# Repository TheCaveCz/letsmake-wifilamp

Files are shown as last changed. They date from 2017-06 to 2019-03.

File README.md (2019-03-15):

# Let's make: WiFi Lamp

ESP8266 chip on Wemos D1 mini module that is driving WS2812 LED strip, one tactile switch for manual control.
Firmware contains HTTP REST API and Blynk platform integration for mobile app control.

More resources:
* [3D prints](stl)
* Firmware
  * [Original](firmware/lm-wifilamp) - uses [Arduino core for ESP8266](https://github.com/esp8266/Arduino), using [Blynk](https://blynk.cc) platform
  * [Tester](firmware/lm-wifilamp-test) - testing sketch
* [Hardware assembly](pictures)
* [PCB drawings](board) - simple PCB to avoid messing with lots of wires. Created in EAGLE 7.7

## Setup

### On your computer

* Install [Arduino core for ESP8266](https://github.com/esp8266/Arduino#installing-with-boards-manager) - **use version 2.4.2 or above**
* Install the [Blynk Arduino library](http://help.blynk.cc/getting-started-library-auth-token-code-examples/how-to-install-blynk-library-for-arduino)
* Install the [WiFi Manager library](https://github.com/tzapu/WiFiManager)
* Compile and upload the [firmware](firmware/lm-wifilamp)

### On your mobile phone

* Install [Blynk app](https://www.blynk.cc/getting-started/)
* Create account or log in
* Create new empty project in Blynk App
* Copy auth token from the app or your email
* Connect to the wifilamp AP
* Wait for WiFi login popup (or use browser and navigate to `http://192.168.4.1`)
* Enter WiFi credentials and auth token
* Setup the Blynk project (see next section)

### Reconfiguring or resetting lamp

* Hold button until the lamp lights up with violet color
* Connect to the wifilamp AP
* Wait for WiFi login popup (or use browser and navigate to `http://192.168.4.1`)
* Enter WiFi credentials and auth token

## Blynk project

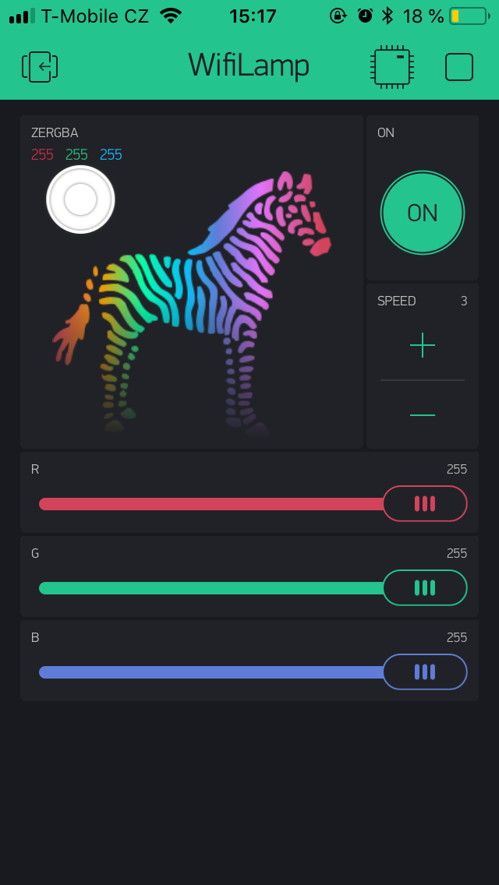
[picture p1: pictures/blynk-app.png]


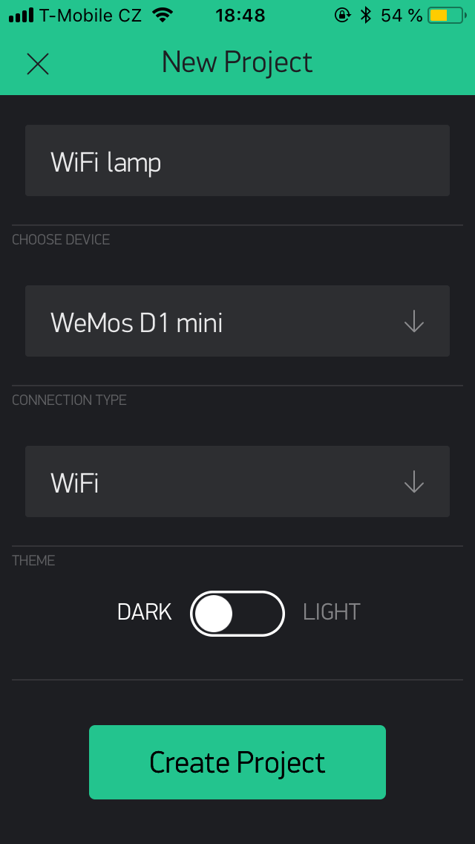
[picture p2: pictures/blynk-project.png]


[Check the video of creating the Blynk project](pictures/blynk-setup.mp4)

<video width="320"><source src="pictures/blynk-setup.mp4" type="video/mp4"></video>

## How it looks

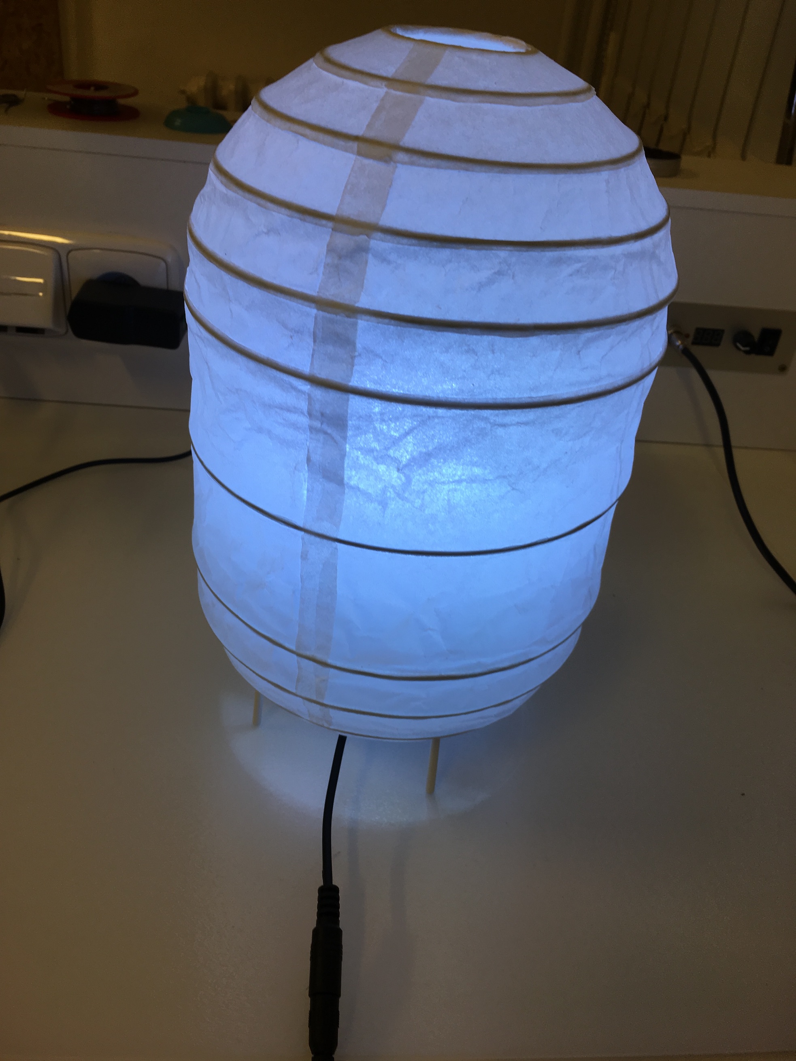
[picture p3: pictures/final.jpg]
The Device


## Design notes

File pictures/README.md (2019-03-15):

# Assembly instructions

## Button box

Slide longer cable assembly into the heat shrink tube. All the way up to the connector
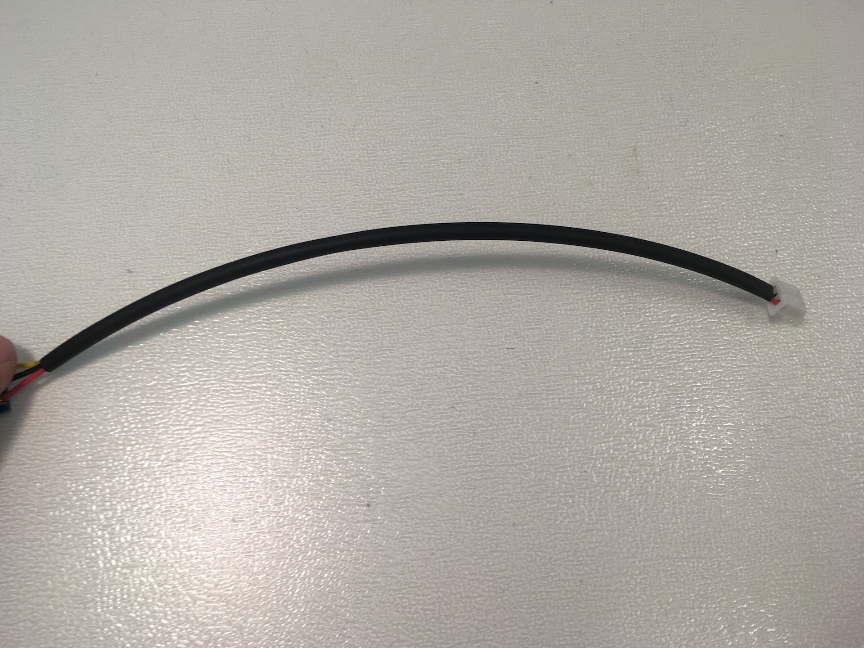
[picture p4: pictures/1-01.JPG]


Solder the wires sticking from the heat shrink tube to the PCB. Mind the correct colors!
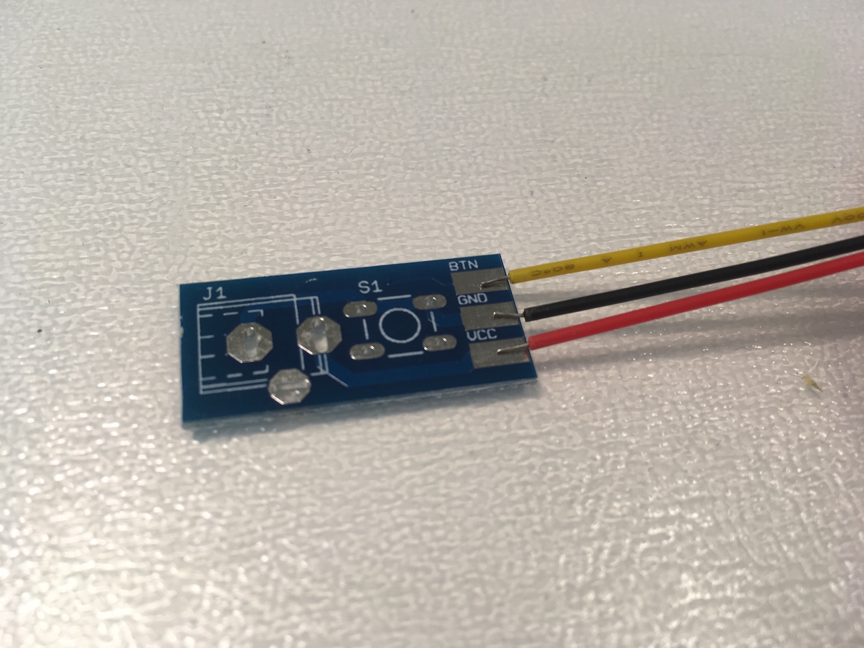
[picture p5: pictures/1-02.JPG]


Solder button and DC jack to the PCB. DC jack needs to lie flat and straight on the PCB. Same for the connector.
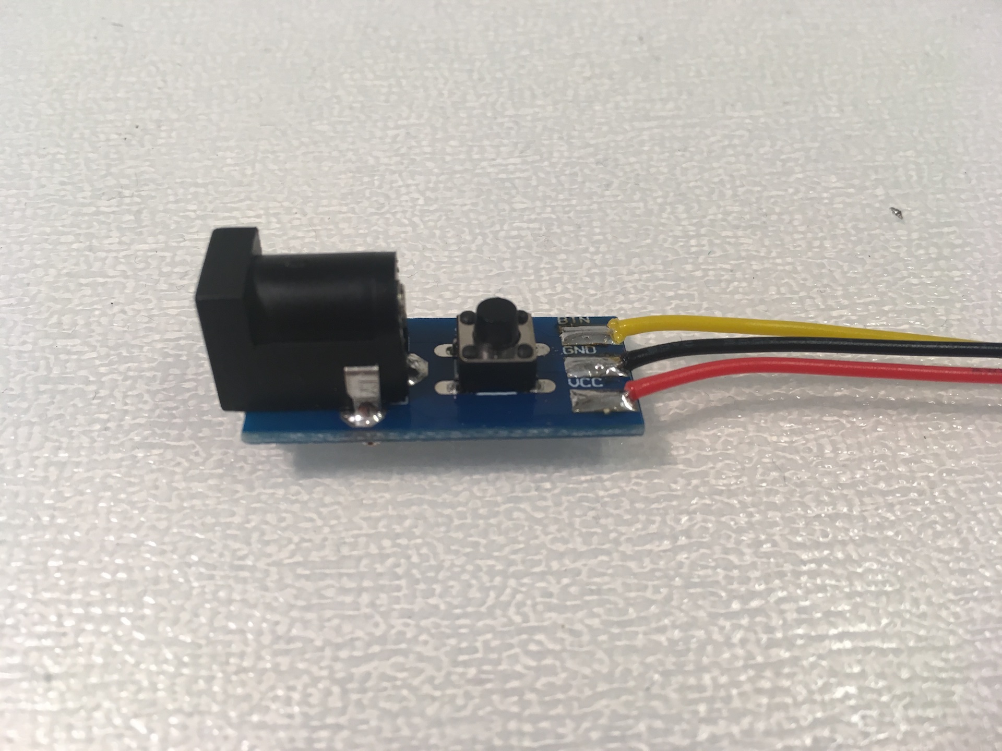
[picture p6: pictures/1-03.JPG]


Move the heatshrink tube all the way to the PCB and shrink it using heat (regular lighter is OK). Place the PCB into the bottom part of the box. It needs to fit precisely into the printed slot in the box.
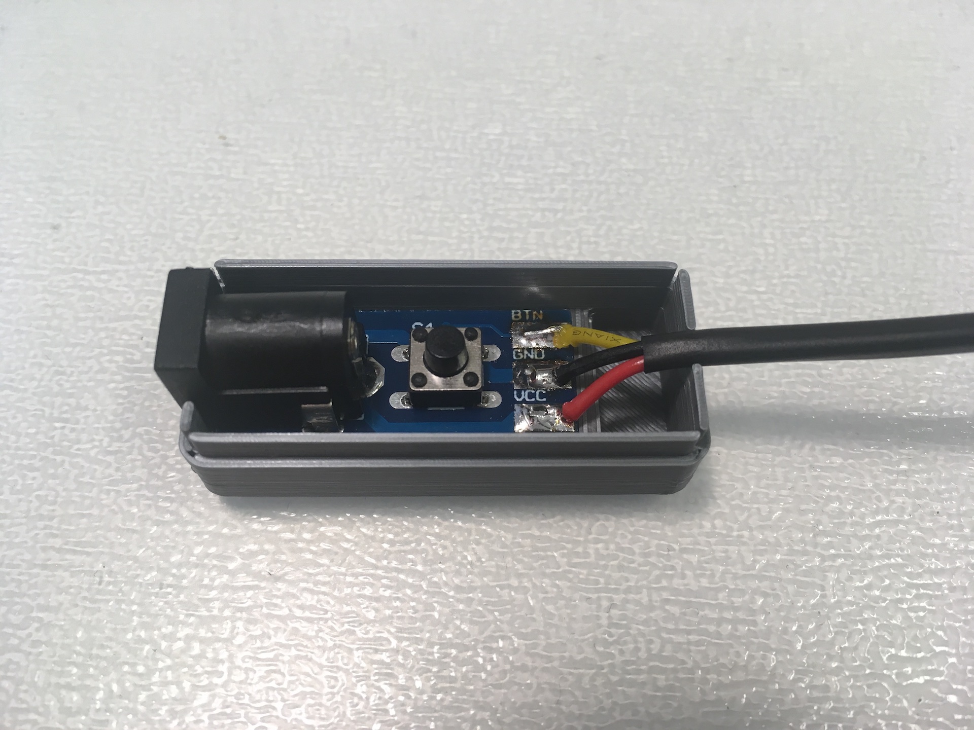
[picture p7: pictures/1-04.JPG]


Place the knob on the switch and cover the box with top part. Button needs to click freely and loudly after the box is closed.
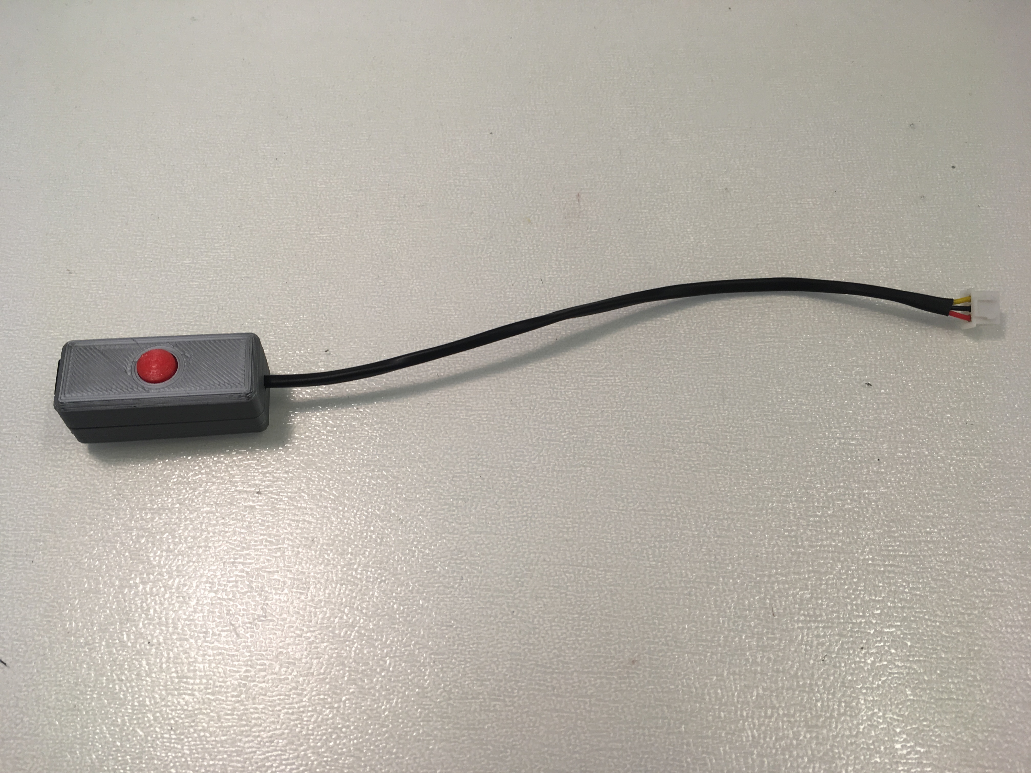
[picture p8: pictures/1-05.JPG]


## LED holder

Solder the wires of the shorter cable assembly onto the LED strip. Mind the correct colors!
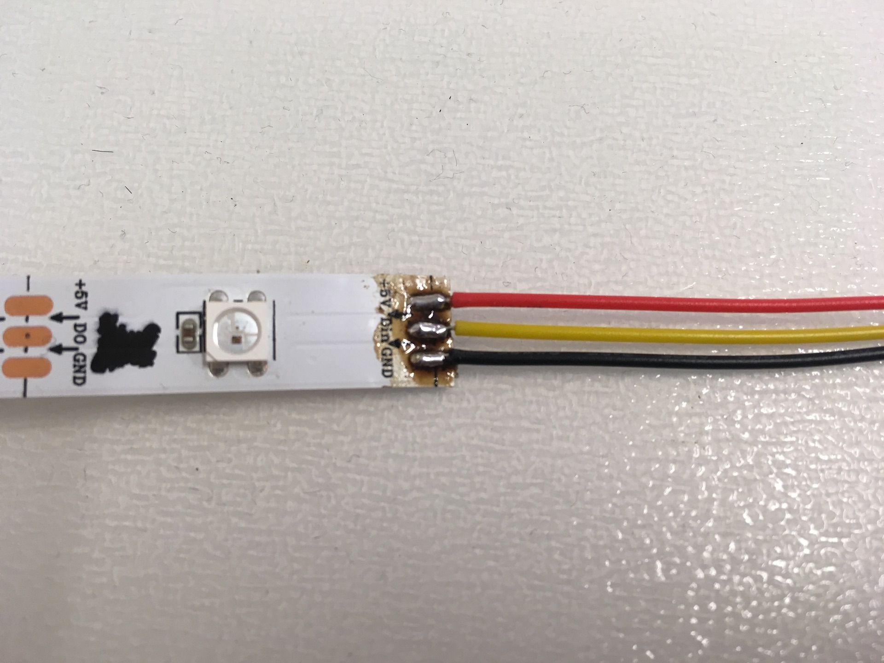
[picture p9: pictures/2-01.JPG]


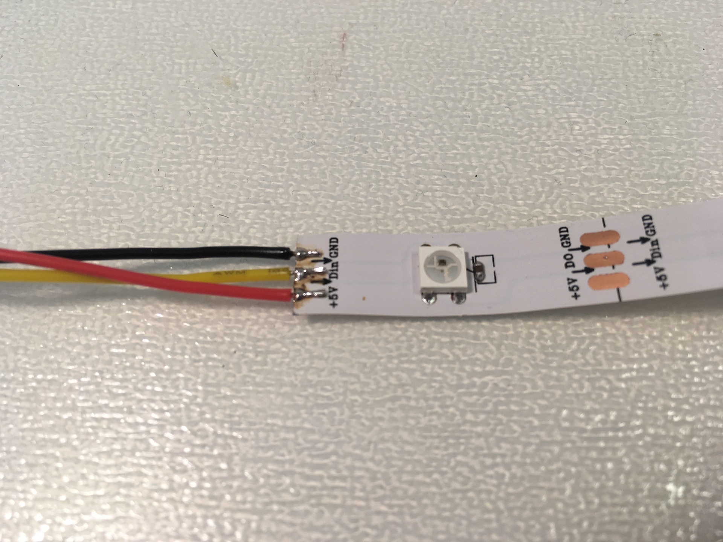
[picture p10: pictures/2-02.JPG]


Stick one piece of paper tape on the top of the aluminium tube.
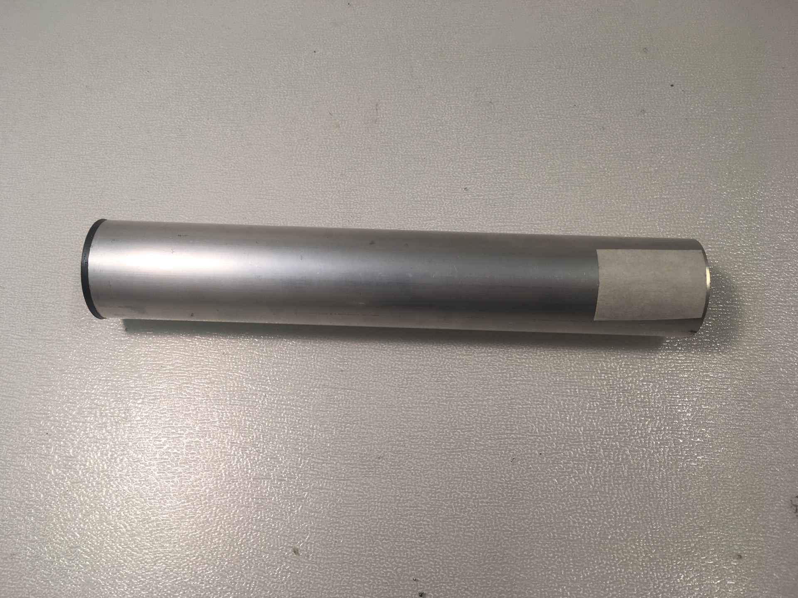
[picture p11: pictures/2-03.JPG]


Stick the LED strip on the tube. Do not stick it all the way to the end for now! Strip must start on the paper tape!
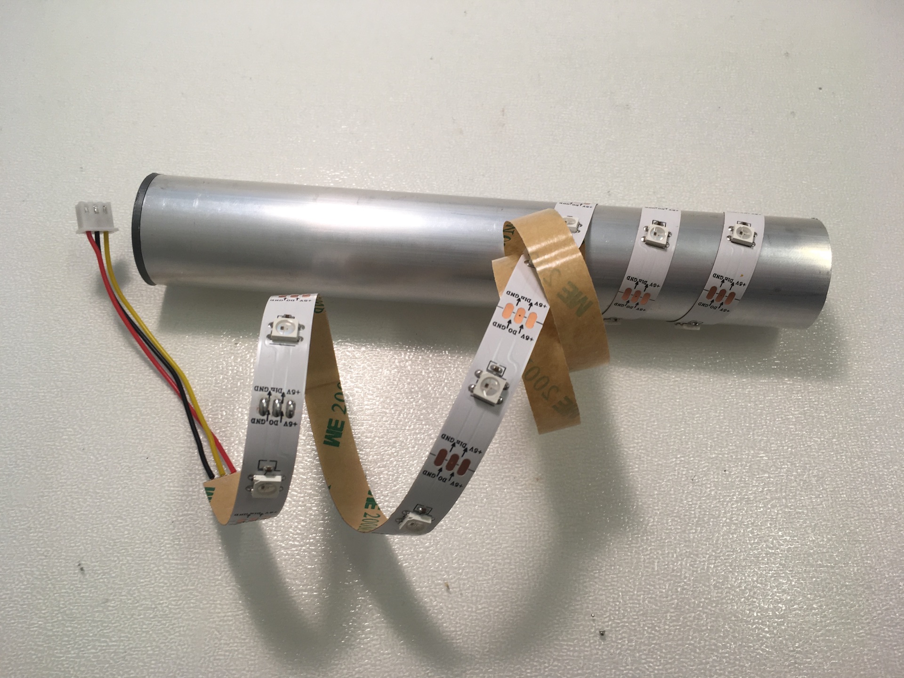
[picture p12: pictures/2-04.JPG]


Stick one piece of paper tape on the place where LED strip will end.
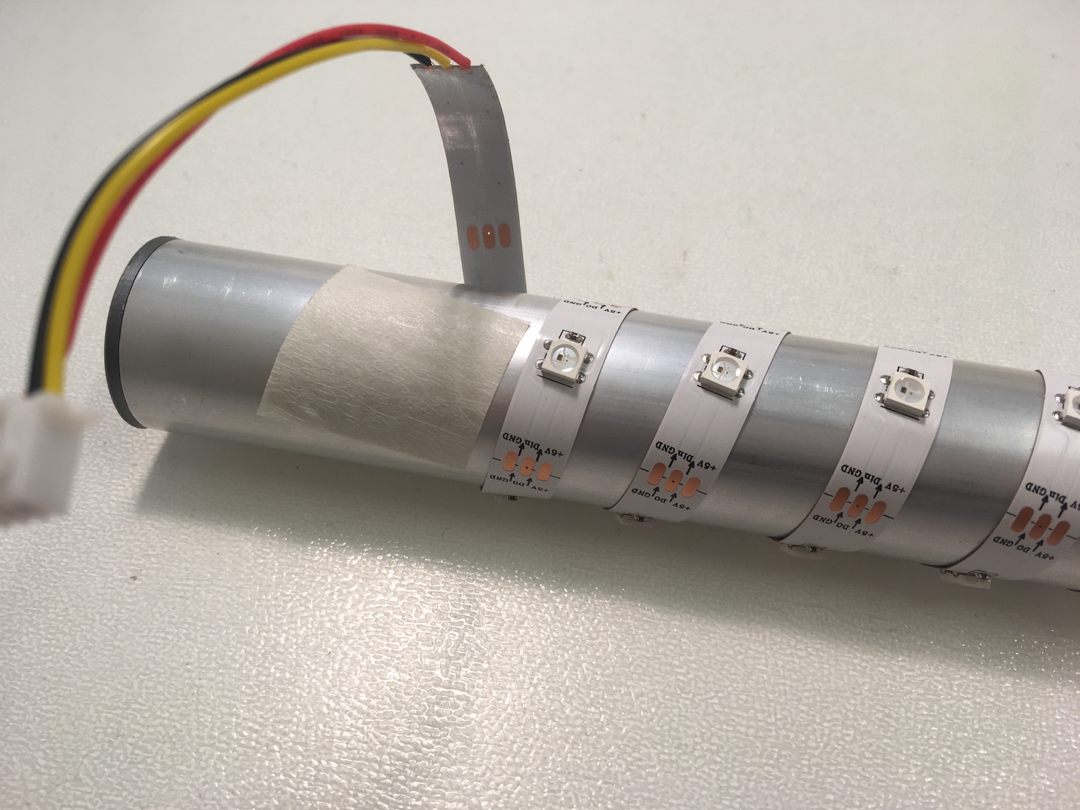
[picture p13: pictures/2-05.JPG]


Finish the LED strip - end of the LED strip must be on the paper tape!
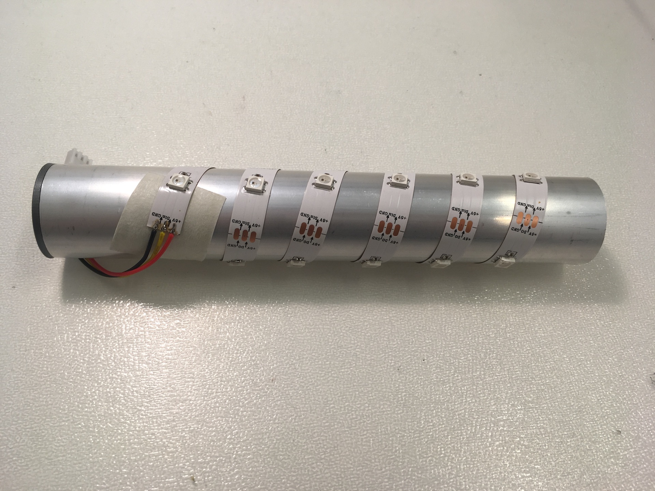
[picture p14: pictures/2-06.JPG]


Secure start of the strip with piece of paper tape.
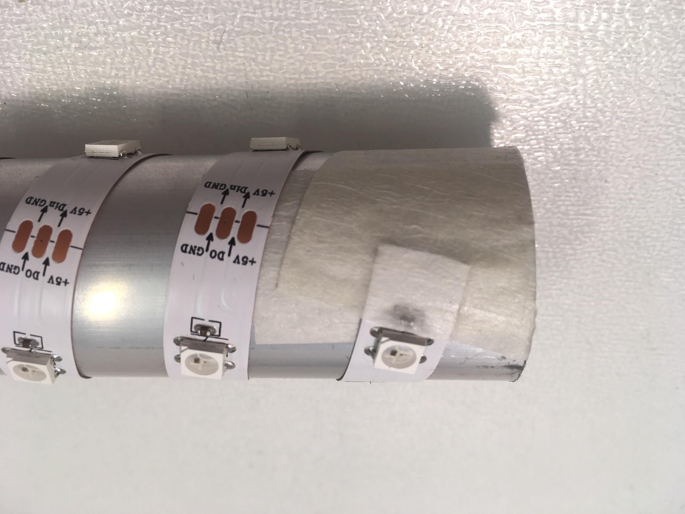
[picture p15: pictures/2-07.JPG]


Secure end of the strip with piece of paper tape.
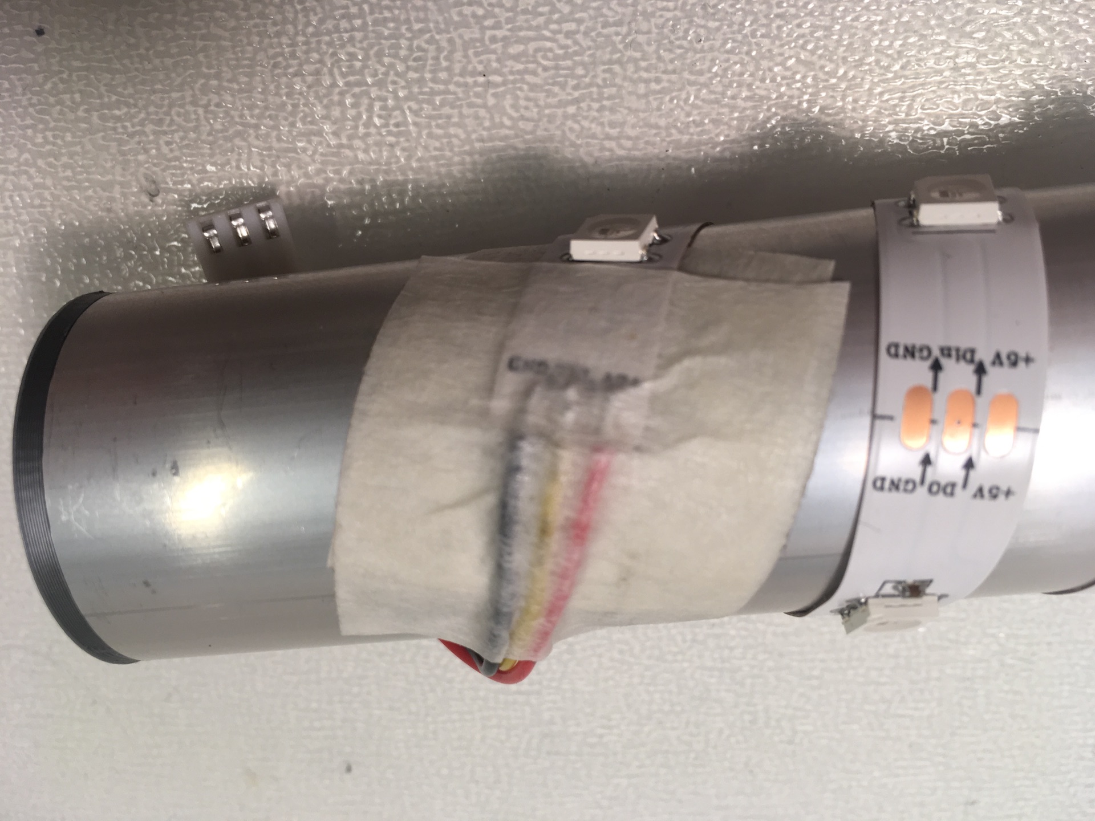
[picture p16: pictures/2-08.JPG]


## Base

Put pin headers into the PCB. Short part of the pin header must face up, long part is in the PCB. Do not solder anything yet!
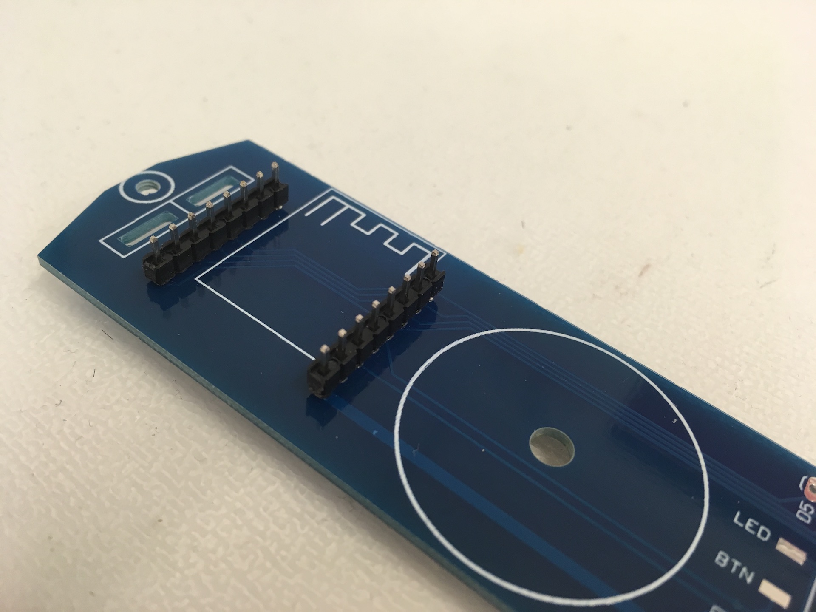
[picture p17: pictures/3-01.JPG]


Place Wemos D1 mini on the short part of the pin headers and solder pin headers to Wemos D1 mini.
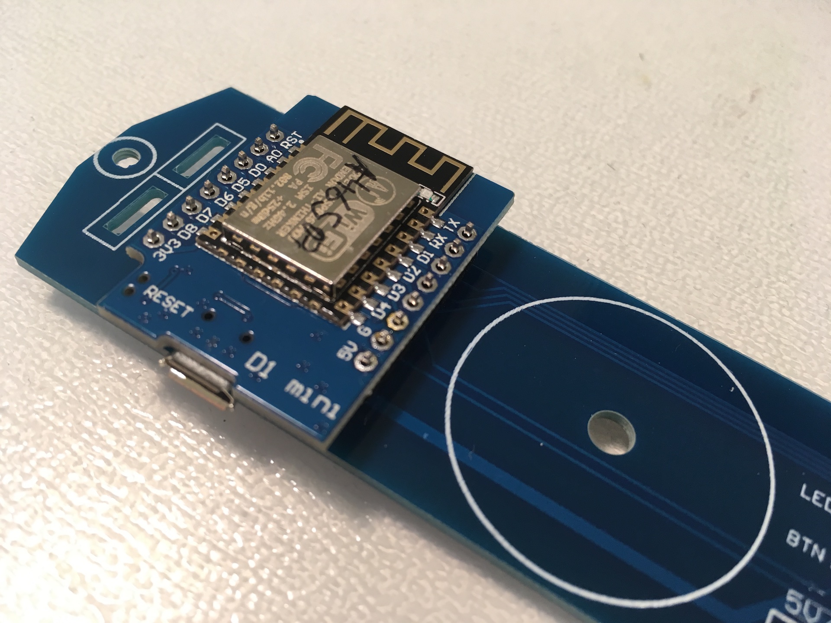
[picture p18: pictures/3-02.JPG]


Pull Wemos D1 mini from the PCB and put at aside for a while.
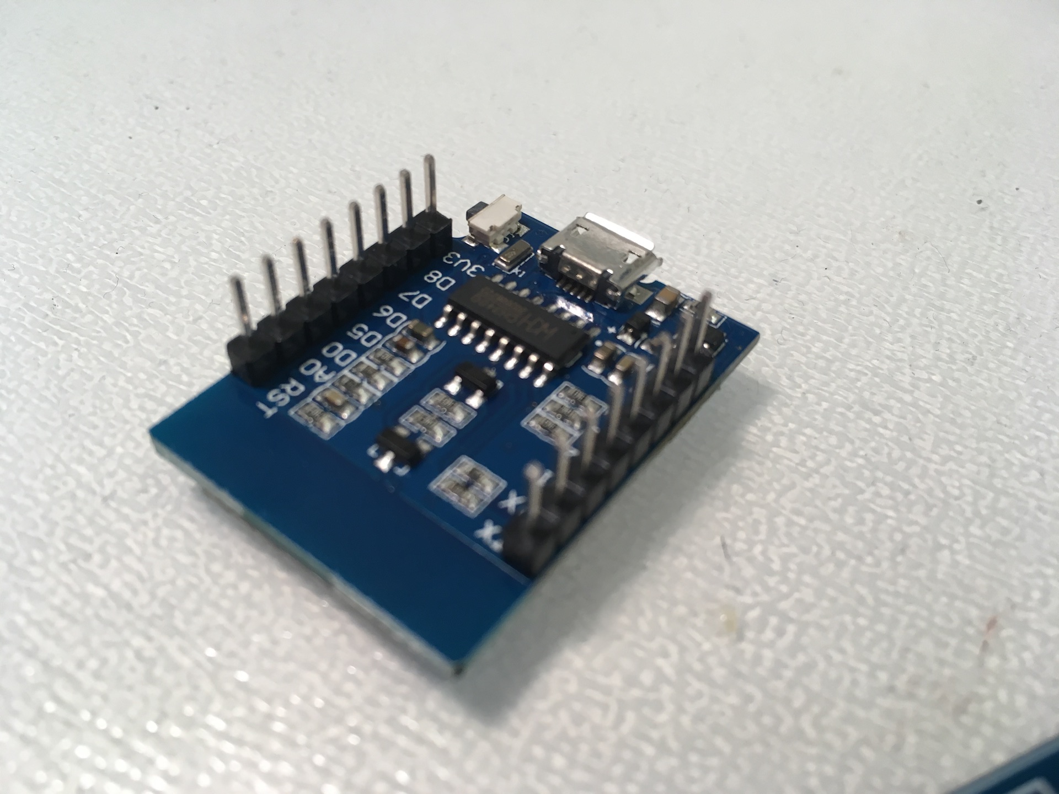
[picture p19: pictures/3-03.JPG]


Solder angle JST connector to the PCB (opening marked PWR). Connector must face out of the PCB
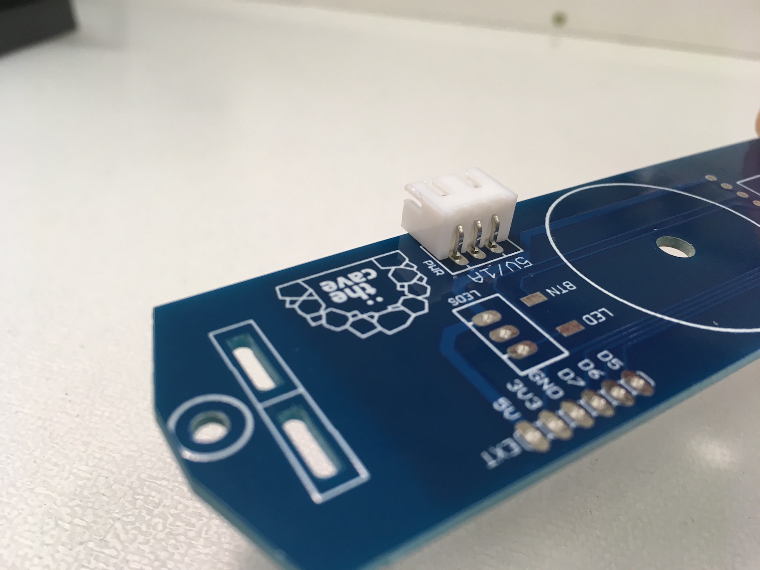
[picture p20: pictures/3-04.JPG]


Solder straight JST connector to the PCB (opening marked LEDS). Mind the correct orientation (connector must line perfectly with the outline on the PCB).
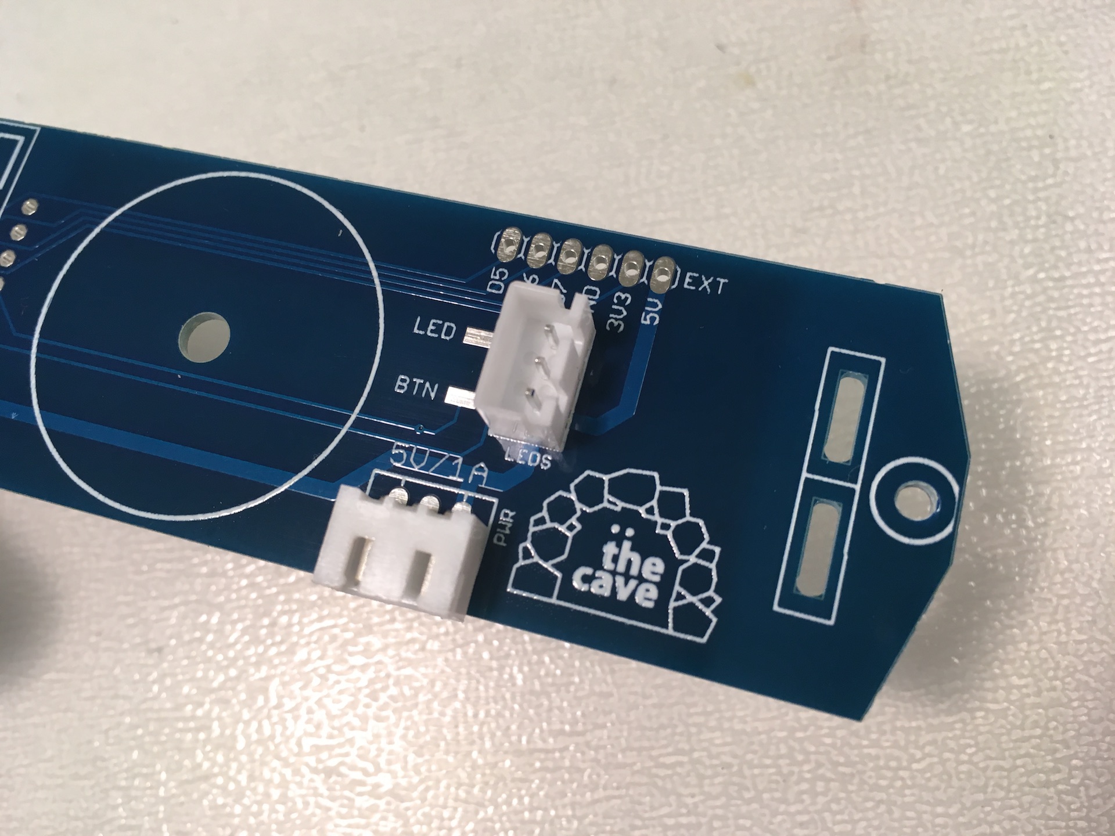
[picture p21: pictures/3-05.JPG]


Put pin header sockets on Wemos D1 mini
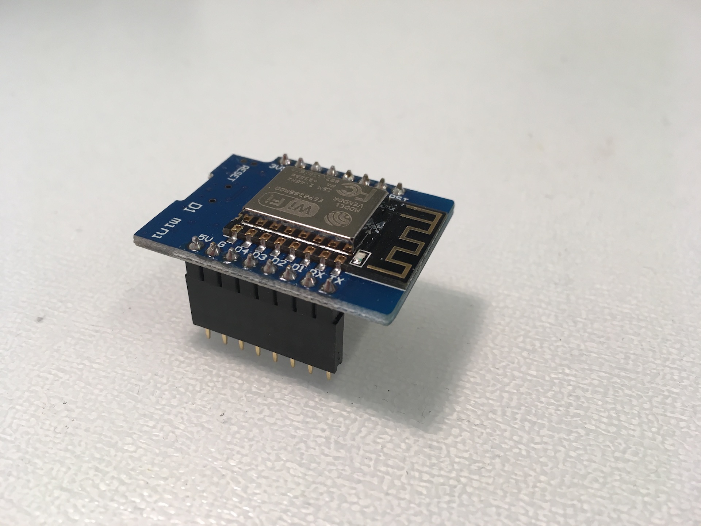
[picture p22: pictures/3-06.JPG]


Solder Wemos D1 mini with sockets to the PCB. Wemos antenna (gold wiggly line) must match with the drawing on the PCB.
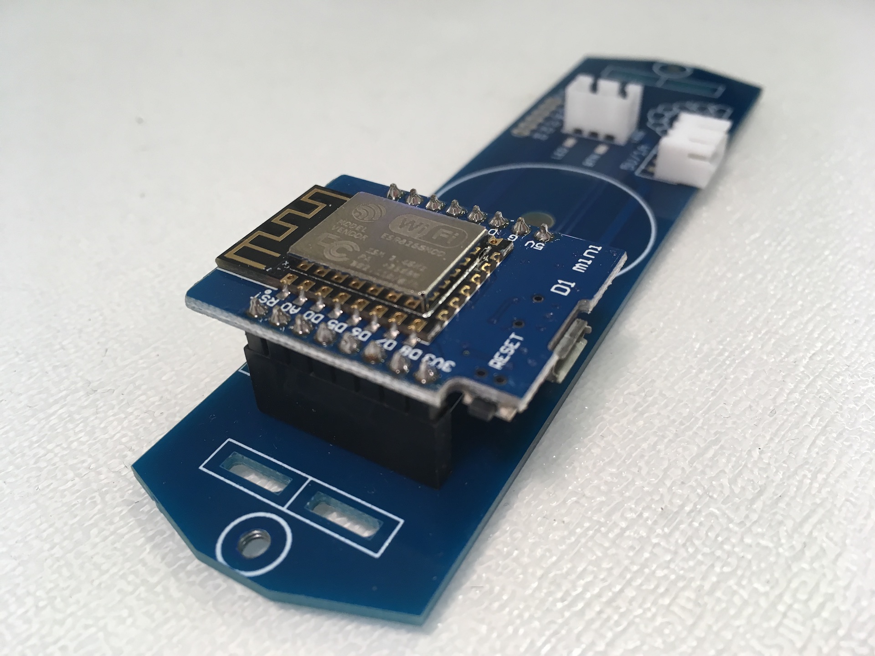
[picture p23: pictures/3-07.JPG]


Pull Wemos D1 mini out of the socket.
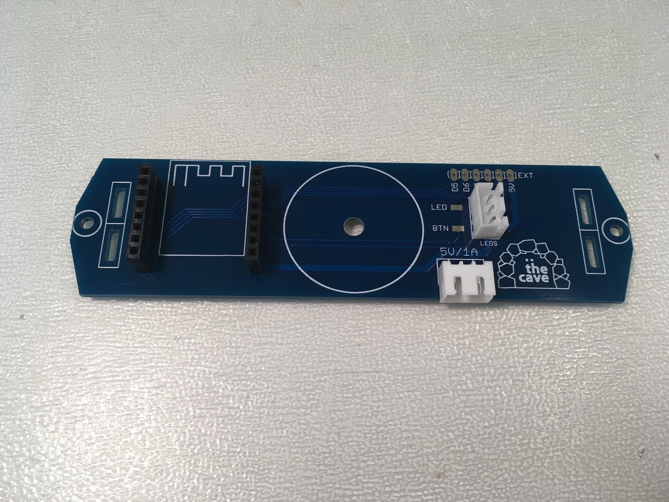
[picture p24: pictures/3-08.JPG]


Put M4 nut into the 3D printed circular holder.
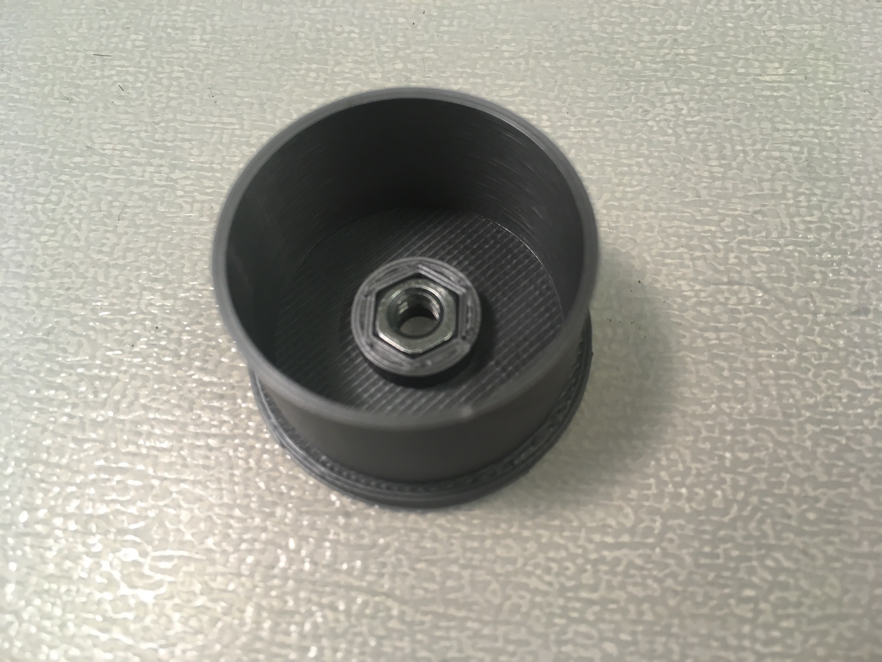
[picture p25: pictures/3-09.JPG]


Put M4 screw into the PCB.
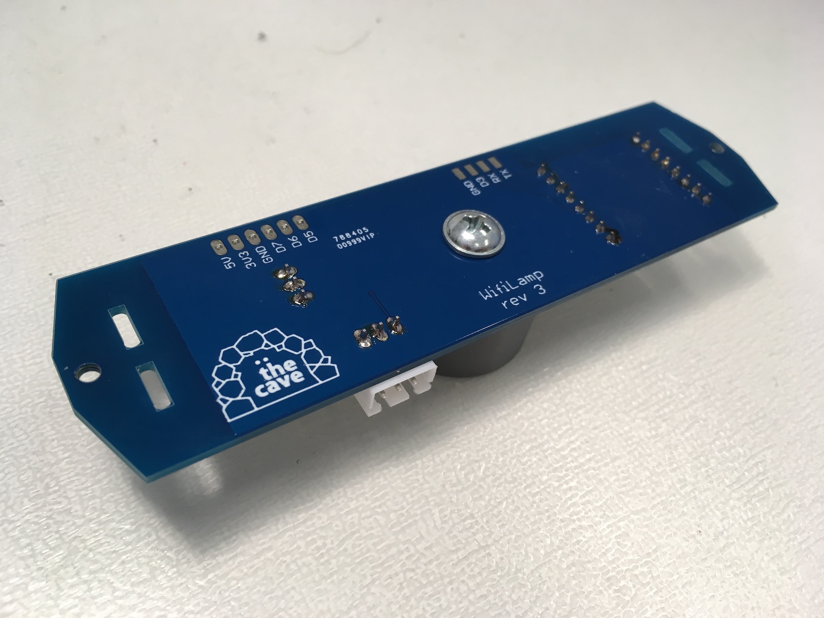
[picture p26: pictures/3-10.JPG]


Screw the 3D printed holder. Do not overtighten.
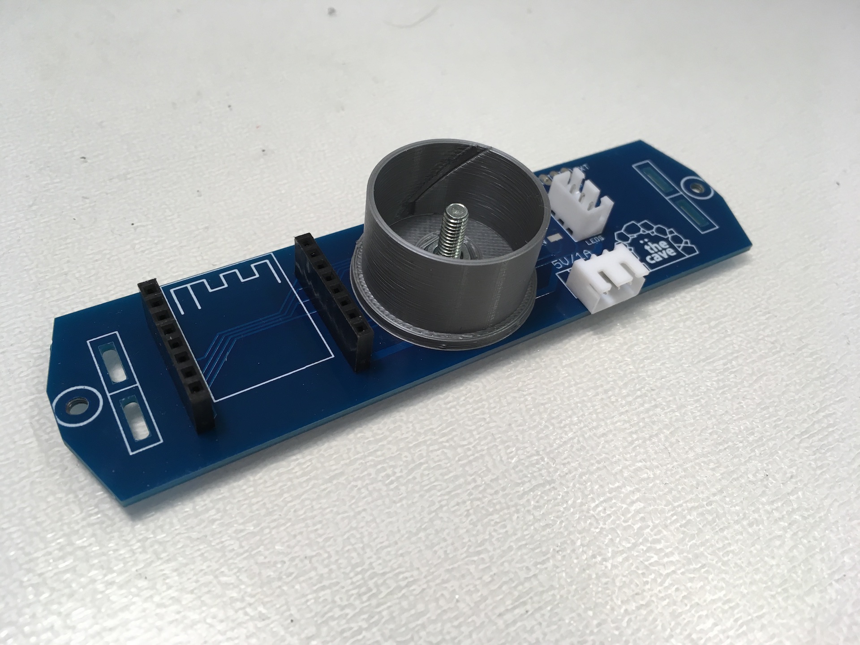
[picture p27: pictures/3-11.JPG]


Slide the tube with LED strip onto the holder and connect the LEDS JST connector. Turn the holder and the tube slightly to straighten the cable.
assembly

Connect the box with button to the PWR JST connector.
assembly

Carefully unpack paper lamp body, turn the PCB assembly around and slide the paper body onto it.
assembly

Screw the M3 screws with the washer into the PCB. Do not overtighten, you can damage the PCB.
assembly

Note the position of the slots in the PCB (next to the screws).
assembly

Put one end of the spring into PCB slot and the other in the hook on the top of the lamp body.
assembly

## Finished

Mechanical assembly is now done! Now you need to setup the WiFi and connect the lamp to Blynk server. 
assembly

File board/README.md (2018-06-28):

# Board

## Main

Schematic

PCB

## Power button

Schematic

PCB

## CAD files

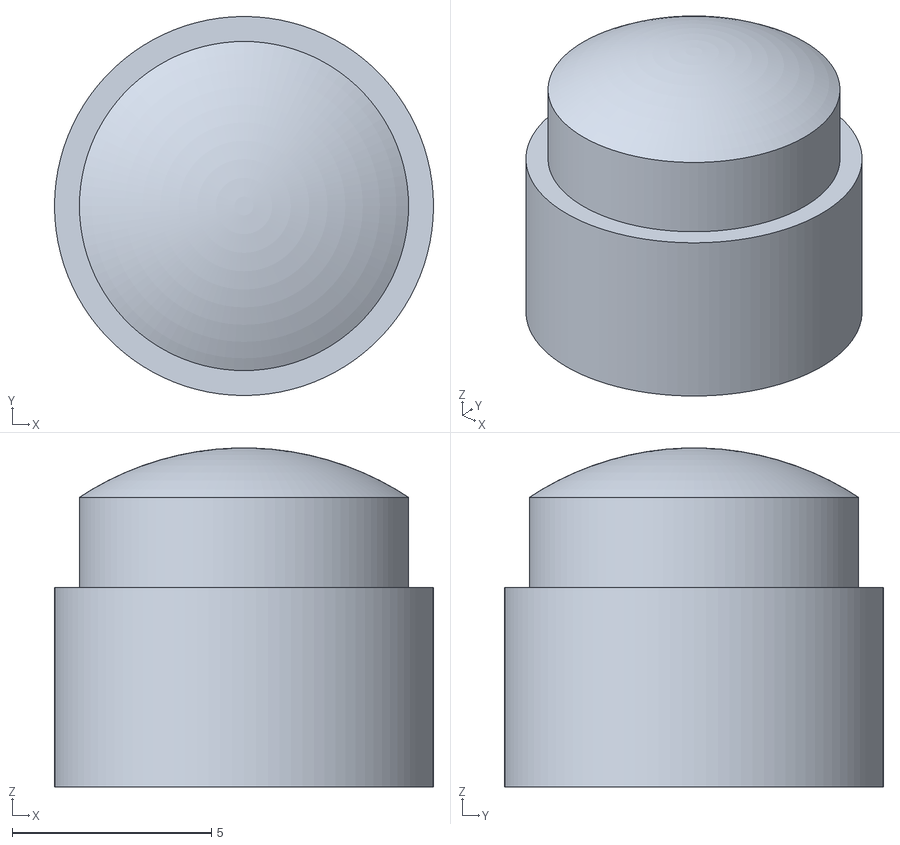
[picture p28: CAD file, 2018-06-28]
stl/button.stl
9.50 x 9.50 x 8.50

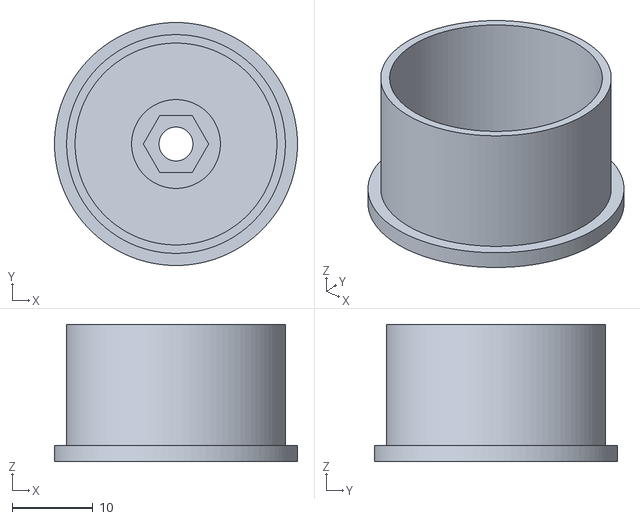
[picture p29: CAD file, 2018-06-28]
stl/led-holder.stl
30.1 x 30.1 x 17.0

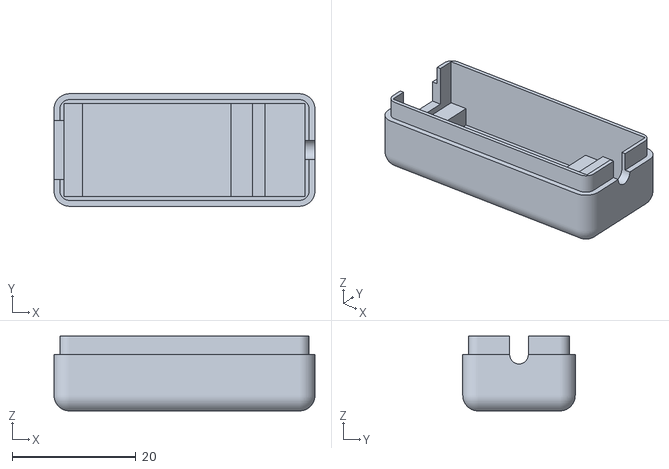
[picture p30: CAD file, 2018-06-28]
stl/power-bottom.stl
42.2 x 18.2 x 12.1

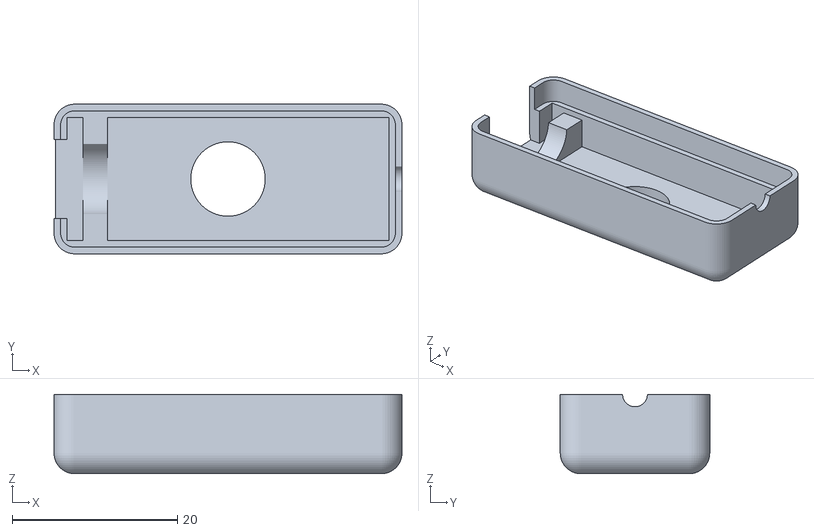
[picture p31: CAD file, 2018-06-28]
stl/power-top.stl
42.1 x 18.1 x 9.60

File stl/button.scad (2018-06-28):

//
//  WifiLamp
//  part of Let's make series
//
//  The Cave, 2018
//  https://thecave.cz
//
//  Licensed under MIT License (see LICENSE file for details)
//

$dia = 8.25;
$rimDia = 9.5;
$holeHeight=0.6;
$rimHeight = $holeHeight+4.4;
$buttonHeight = $rimHeight+4;

difference() {
    union() {
        cylinder(d=$rimDia,h=$rimHeight,$fn=100);
        intersection() {
            cylinder(d=$dia,h=$buttonHeight,$fn=100);
            translate([0,0,1]) sphere(d=15,$fn=100);
        }
    }
    translate([0,0,-1]) cylinder(d=4,h=1 + $holeHeight, $fn=100);
}

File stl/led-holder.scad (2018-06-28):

//
//  WifiLamp
//  part of Let's make series
//
//  The Cave, 2018
//  https://thecave.cz
//
//  Licensed under MIT License (see LICENSE file for details)
//

$ledHolderOuterDia = 27.1;
$ledHolderInnerDia = 25;
$ledHolderRimThickness = 1.5;
$ledHolderHeight = 15;

$baseThickness = 2;

$nutInsertDia = 11;
$nutDia = 8.1;
$nutThickness = 3;
$nutSides = 6;


module base() {
    difference() {
        cylinder(h=$baseThickness+$ledHolderHeight,d=$ledHolderOuterDia,$fn=100);
        translate([0,0,-1]) cylinder(h=$baseThickness+$ledHolderHeight+2,d=$ledHolderInnerDia,$fn=100);
    }
    cylinder(h=$baseThickness,d=$ledHolderOuterDia+$ledHolderRimThickness*2,$fn=100);
}

module nutInsert() {
    difference() {
        cylinder(d=$nutInsertDia,h=$nutThickness,$fn=100);
        translate([0,0,-1]) cylinder(d=$nutDia,h=$nutThickness+2,$fn=$nutSides);
    }
}

difference() {
    union() {
        base();
        translate([0,0,$baseThickness]) nutInsert();
    }
    translate([0,0,-1]) cylinder(d=4.2,h=$baseThickness+2,$fn=100);
}

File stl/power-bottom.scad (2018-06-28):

//
//  WifiLamp
//  part of Let's make series
//
//  The Cave, 2018
//  https://thecave.cz
//
//  Licensed under MIT License (see LICENSE file for details)
//

$innerX = 39;
$innerY = 15;
$outerZ = 12.1;
$wall = 1.6;
$outerDia = 5;
$dentZ = 3;

$powerWidth = 9.5;


module bottomBase() {
    difference() {
        translate([$outerDia/2,$outerDia/2,$outerDia/2]) minkowski() {
            sphere(d=$outerDia,$fn=50);
            cube([$innerX+$wall*2-$outerDia,$innerY+$wall*2-$outerDia,$outerZ+$outerDia*2]);
        }
        translate([$wall,$wall,$wall]) cube([$innerX,$innerY,$outerZ*2]);
        translate([-1,-1,$outerZ-$dentZ]) cube([$innerX*2,$innerY*2,$outerZ*2]);
    }
}

module bottomDent() {
    translate([$outerDia/2,$outerDia/2,$outerZ-$dentZ]) difference() {
        minkowski() {
            cube([$innerX+$wall-($outerDia-$wall),$innerY+$wall-($outerDia-$wall),$dentZ/2]);
            cylinder(d=$outerDia-$wall-0.3,h=$dentZ/2,$fn=50);
        }
        translate([-$outerDia/2+$wall,-$outerDia/2+$wall,-1]) cube([$innerX,$innerY,$dentZ+2]);
    }
}

module bottomSupports() {
    translate([$wall,$wall,$wall]) cube([3, $innerY, 3]);
    translate([$wall+27,$wall,$wall]) cube([4,$innerY,3]);
    translate([$wall+30.5,$wall,$wall]) cube([2,$innerY,4]);
}

module bottom() {
    difference() {
        union() {
            bottomBase();
            bottomDent();
        }
        translate([$innerX+$wall-1,$wall+$innerY/2,$outerZ-$dentZ]) {
            translate([0,-1.5,0]) cube([$wall+2, 3, 100]);
            rotate([0,90,0]) cylinder(d=3,h=$wall+2,$fn=100);
        }
        translate([-1,$wall+($innerY-$powerWidth)/2,$wall+4]) cube([$wall+2,$powerWidth, 100]);
    }
    bottomSupports();
}

bottom();

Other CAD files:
stl/power-top.scad

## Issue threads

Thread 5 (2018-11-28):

Can't compile firmware (D2 not declared in scope)

krystof-riha, 2018-11-28:
I was unable the compile the firmware, as 'D2' (defined as BUTTON_PIN) is apparently not declared.

```/home/kriha/Work/prototypes/letsmake-wifilamp/firmware/lm-wifilamp/x04_button.ino: In function 'void buttonSetup()':
x04_button:32:20: error: 'D2' was not declared in this scope
/home/.../letsmake-wifilamp/firmware/lm-wifilamp/x04_button.ino:3:11: note: in expansion of macro 'BUTTON_PIN'
   pinMode(BUTTON_PIN, INPUT_PULLUP);
           ^
/home/kriha/Work/prototypes/letsmake-wifilamp/firmware/lm-wifilamp/x04_button.ino: In function 'uint8_t buttonReadRaw()':
x04_button:32:20: error: 'D2' was not declared in this scope
/home/kriha/Work/prototypes/letsmake-wifilamp/firmware/lm-wifilamp/x04_button.ino:7:22: note: in expansion of macro 'BUTTON_PIN'
   return digitalRead(BUTTON_PIN) == LOW;
                      ^
exit status 1
'D2' was not declared in this scope```

dzindra, 2018-11-28:
You probably forgot to select proper board in Tools menu in Arduino IDE

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

krystof-riha, 2018-11-28:
Ohh my bad, I selected `Generic ESP8266 Module`
Thanks, I'll close this now

Closed 2018-11-28.

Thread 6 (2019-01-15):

WiFi credentials are not loaded after restart

arnostpleskot, 2019-01-15:
Hi!

I've updated the firmware to the latest version (current master branch) and after that, I'm not able setup WiFi connection. According to logs, Arduino does not have any saved credentials after WiFi reset. But blynk token is saved and read properly...

Log:
```
*WM: Handle root
*WM: Scan done
*WM: DUP AP: UPC Wi-Free
*WM: wf_degu_and_cats
*WM: -58
*WM: UPC Wi-Free
*WM: -59
*WM: UPC13C35F7
*WM: -63
*WM: Miska
*WM: -75
*WM: Sent config page
*WM: WiFi save
*WM: Parameter
*WM: token
*WM: *****SOME_SAVED_BLYNK_TOKEN*****
*WM: Sent wifi save page
*WM: Connecting to new AP
*WM: Connecting as wifi client...
[63958] WiFi connected successfuly
[63958] Got IP: 192.168.0.10
*WM: Connection result:
*WM: 3
[64102] Config should be saved
[64102] Writing config
*WM: freeing allocated params!
[64103] Blynk v0.5.4 on Arduino
[64103] Ready to go!
[64106] Pixels anim state set to 3
[64106] Blynk connect attempt
[64109] Connecting to blynk-cloud.com:80
[69110] Connecting to blynk-cloud.com:80
[69177] Ready (ping: 36ms).
[69244] Blynk connected
[69245] Pixels anim state set to 4
[69332] Logic state 1
[72558] WiFi reset in progress

 ets Jan  8 2013,rst cause:2, boot mode:(3,6)

load 0x4010f000, len 1384, room 16
tail 8
chksum 0x2d
csum 0x2d
vbb28d4a3
~ld
[44] Starting
[44] Chip id: acc65
[45] Reading config
[45]  blynk token: *****SOME_SAVED_BLYNK_TOKEN*****
[125] Connecting to WiFi...
[125] Pixels anim state set to 0
[126] No saved credentials
[126] Pixels anim state set to 1
*WM: Adding parameter
*WM: token
*WM:
*WM: Configuring access point...
*WM: wifilamp-acc65
*WM: AP IP address:
*WM: 192.168.4.1
*WM: HTTP server started
```

WiFiManager version: 0.14.0
Arduino core for ESP8266 version: 2.4.2
Firmware commit: 4073a39842b6708a7eb67d884f8de1cf408a1944

Thank you for help!

dzindra, 2019-01-21:
It seems like you have older hardware revision. New firmware is using different pins. You should change [lm-wifilamp.ino](https://github.com/TheCaveCz/letsmake-wifilamp/blob/master/firmware/lm-wifilamp/lm-wifilamp.ino#L32), line 32 from

```
#define BUTTON_PIN D2
```

to

```
#define BUTTON_PIN D5
```
and replace [x04-button.ino](https://github.com/TheCaveCz/letsmake-wifilamp/blob/master/firmware/lm-wifilamp/x04_button.ino) with

```
void buttonSetup() {
  pinMode(BUTTON_PIN, INPUT);
}

uint8_t buttonReadRaw() {
  return digitalRead(BUTTON_PIN) == HIGH;
}
```

Also don't forget to connect pins D1 and D4 together with a piece of wire.

Closed 2019-01-21.

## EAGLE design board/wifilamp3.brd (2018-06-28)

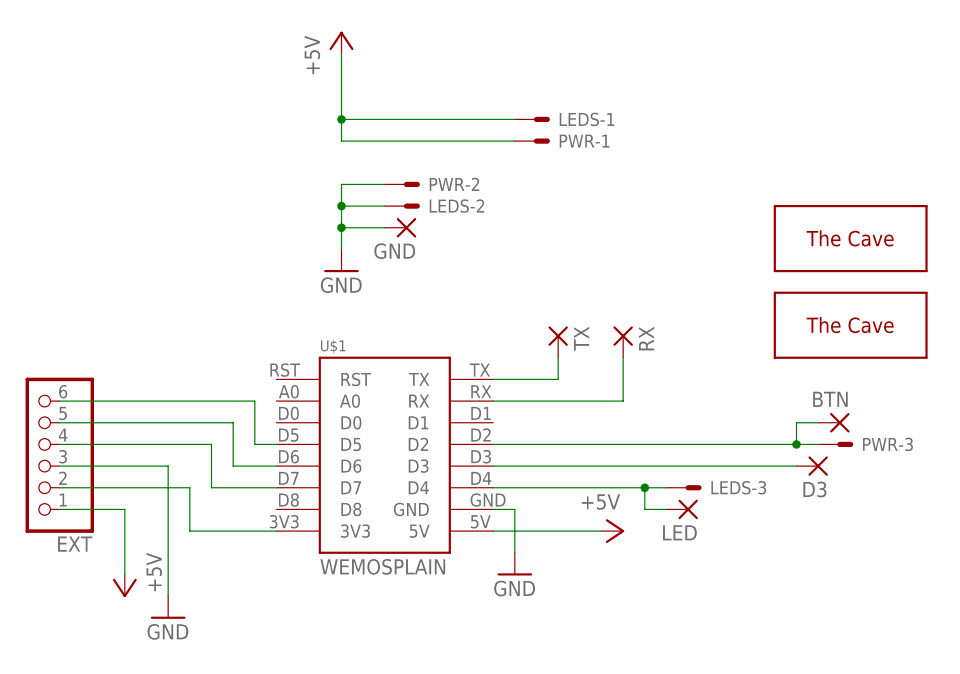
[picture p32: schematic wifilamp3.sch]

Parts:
BTN: WIREPADSMD1,27-254; SMD1,27-2,54
D3: WIREPADSMD1,27-254; SMD1,27-2,54
EXT: PINHD-1X6; 1X06
GND: WIREPADSMD1,27-254; SMD1,27-2,54
LED: WIREPADSMD1,27-254; SMD1,27-2,54
LEDS: JST-XH-03-PIN-LONG-PAD; JST-XH-03-PACKAGE-LONG-PAD
PWR: JST-XH-03-PIN-LONG-PAD; JST-XH-03-PACKAGE-LONG-PAD
RX: WIREPADSMD1,27-254; SMD1,27-2,54
TX: WIREPADSMD1,27-254; SMD1,27-2,54
U$1: WEMOSPLAIN; WEMOS-PLAIN
U$2: THECAVE_LOGO_TOP_MEDIUM; LOGO_TOP_MED
U$3: THECAVE_LOGO_BOTTOM_MEDIUM; LOGO_BOT_MED

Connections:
+5V: EXT.1, LEDS.1, PWR.1, U$1.5V
GND: EXT.3, GND.1, LEDS.2, PWR.2, U$1.GND
unnamed: LED.1, LEDS.3, U$1.D4
unnamed: BTN.1, PWR.3, U$1.D2
unnamed: TX.1, U$1.TX
unnamed: EXT.2, U$1.3V3
unnamed: EXT.4, U$1.D7
unnamed: EXT.5, U$1.D6
unnamed: EXT.6, U$1.D5
unnamed: RX.1, U$1.RX
unnamed: D3.1, U$1.D3

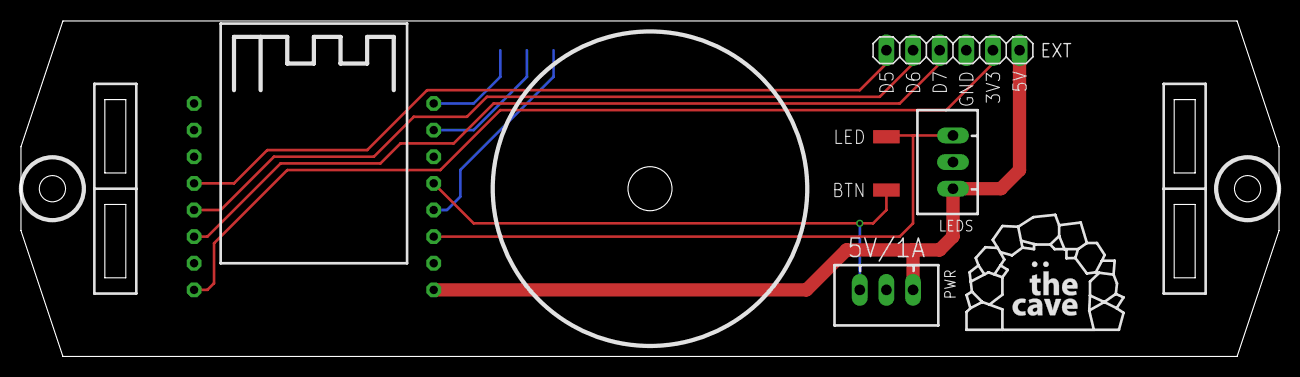
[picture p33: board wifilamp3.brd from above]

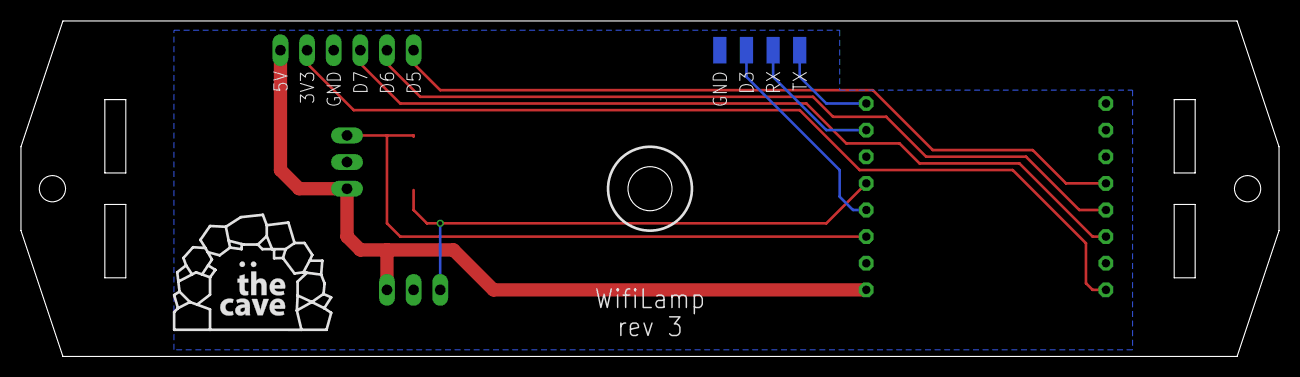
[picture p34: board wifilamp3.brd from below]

Board: 2 copper layers, 120.0 x 32.0 mm, 12 parts (4 on the bottom side), 11 nets.

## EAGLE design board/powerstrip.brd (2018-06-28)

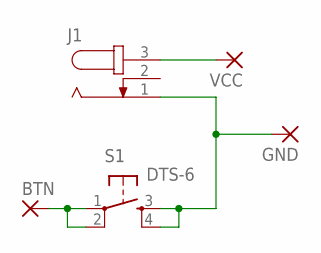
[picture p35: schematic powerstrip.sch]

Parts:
BTN: WIREPADSMD2,54-5,08; SMD2,54-5,08
GND: WIREPADSMD2,54-5,08; SMD2,54-5,08
J1: PC-GK210; PC-GK21
S1: DTS-6
VCC: WIREPADSMD2,54-5,08; SMD2,54-5,08

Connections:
unnamed: J1.3, VCC.1
unnamed: BTN.1, S1.1, S1.2
unnamed: GND.1, J1.1, S1.3, S1.4

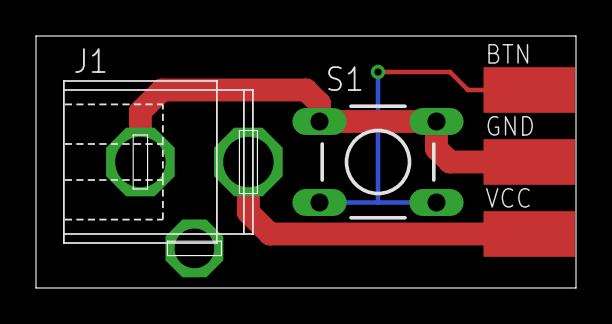
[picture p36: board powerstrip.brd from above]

Board: 2 copper layers, 30.0 x 14.0 mm, 5 parts (0 on the bottom side), 3 nets.

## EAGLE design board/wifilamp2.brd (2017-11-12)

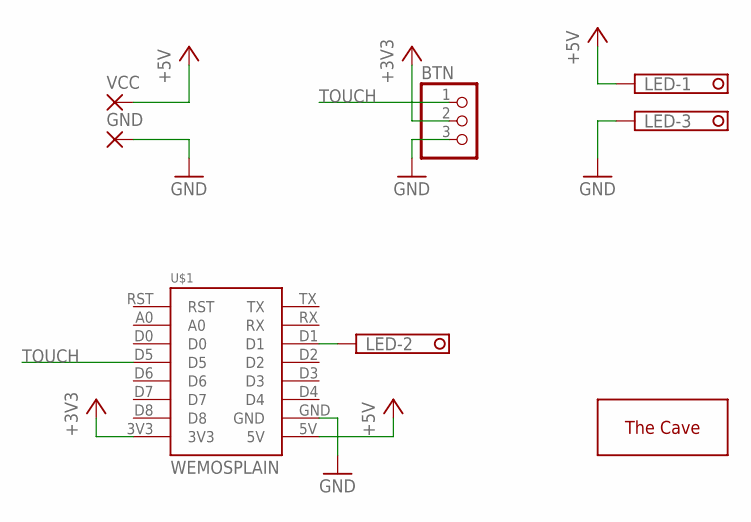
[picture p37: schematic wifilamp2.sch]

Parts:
BTN: PINHD-1X3; 1X03
GND: WIREPAD3,81/1,4; 3,81/1,4
LED: 1751251
U$1: WEMOSPLAIN; WEMOS-PLAIN
U$2: THECAVE_LOGO_TOP_SMALL; LOGO_TOP_SMALL
VCC: PAD3,81/2

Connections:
+3V3: BTN.2, U$1.3V3
+5V: LED.1, U$1.5V, VCC.1
GND: BTN.3, GND.1, LED.3, U$1.GND
unnamed: LED.2, U$1.D1
TOUCH: BTN.1, U$1.D5

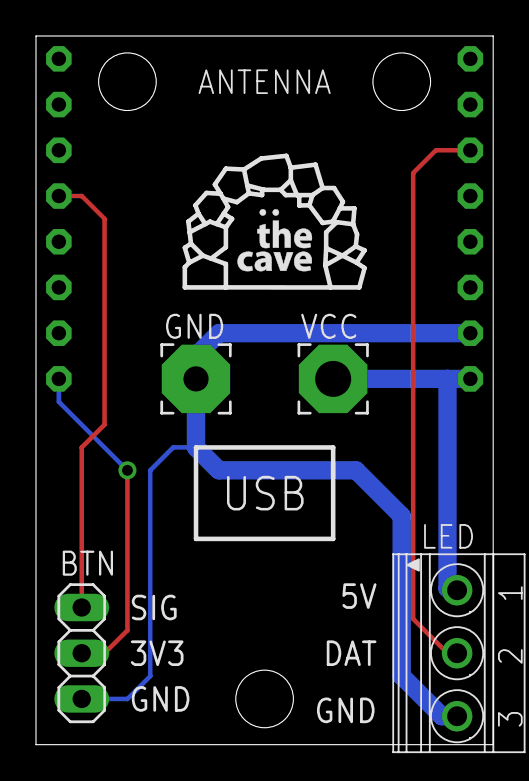
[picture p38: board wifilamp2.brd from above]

Board: 2 copper layers, 25.4 x 39.4 mm, 6 parts (0 on the bottom side), 5 nets.

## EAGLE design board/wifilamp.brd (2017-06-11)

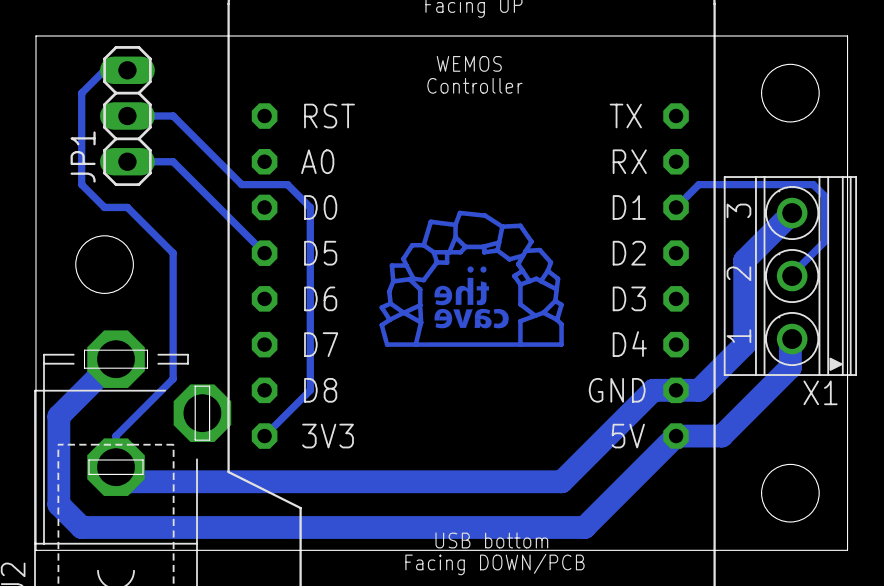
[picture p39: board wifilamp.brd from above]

Board: 2 copper layers, 45.1 x 28.6 mm, 5 parts (1 on the bottom side), 5 nets.

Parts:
J2: PC-GK21
JP1: 1X03
U$1: WEMOS
U$2: THECAVE_LOGO_COPPER_SMALL; COPPER_SMALL
X1: 1751251

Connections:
+3V3: JP1.2, U$1.3V3
+5V: J2.3, U$1.5V, X1.1
GND: J2.1, JP1.3, U$1.GND, X1.3
unnamed: U$1.D1, X1.2
TOUCH: JP1.1, U$1.D5

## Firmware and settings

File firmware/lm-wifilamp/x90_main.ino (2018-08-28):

void setup() {
  Serial.begin(115200);

  logInfo("Starting");
  logValue("Chip id: ", chipId);

  buttonSetup();
  pixelsSetup();

  logicSetup();

  configSetup();
  otaSetup();
  wifiSetup();
  serverSetup();
  blynkSetup();
  logInfo("Ready to go!");
  timeoutRefresh();
}

void loop() {
  if (Blynk.connected()) {
    Blynk.run();
  }

  ArduinoOTA.handle();
  server.handleClient();
  logicButtonTask();

  if (wifiGotIpFlag) {
    wifiGotIpFlag = false;

    if (blynkIsConfigured()) {
      // we have blynk token, try to connect there
      pixelsSetAnimState(PIXELS_ANIM_GREEN);
      timeoutRefresh();
      blynkConnectIfPossible();
    } else {
      // if we don't have blynk token stop pulsing LEDs.
      timeoutClear();
    }
  }

  timeoutCheck();
  blynkCheck();
}

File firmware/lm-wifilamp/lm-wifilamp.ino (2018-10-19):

/*
 * WifiLamp firmware for Blynk app
 */
#define BLYNK_PRINT Serial
#define BLYNK_NO_FANCY_LOGO

#include <ESP8266WiFi.h>
#include <BlynkSimpleEsp8266.h>
#include <ESP8266mDNS.h>
#include <ArduinoOTA.h>
#include <WiFiManager.h>
#include <Ticker.h>
#include <EEPROM.h>
#include "ws2812.h"


// Firmware updates over-the-air will require admin password.
//#define OTA_PASSWORD "mySecretPassword"

// Enable HTTP OPTIONS method response handler - useful for remote webpage debugging
#define OPTIONS_ENABLED 0

// Serial port logging
#define LOG_ENABLED 1

// Password for http api, comment out to disable
#define API_PASSWORD "wifilamp"


#define PIXELS_COUNT 15

#define BUTTON_PIN D2

#define BLYNK_RGB_PIN V0
#define BLYNK_BUTTON_PIN V1
#define BLYNK_RGB_R_PIN V2
#define BLYNK_RGB_G_PIN V3
#define BLYNK_RGB_B_PIN V4
#define BLYNK_SPEED_PIN V5
#define BLYNK_BRIGHTNESS_PIN V6

#define HOSTNAME_PREFIX "wifilamp-"

#define LOGIC_BUTTON_TASK_INTERVAL 20UL
#define LOGIC_BUTTON_LOCKUP_TIME 500UL

#define TIMEOUT_INTERVAL 20000UL
#define RECONNECT_INTERVAL 60000UL

#define FW_VERSION "4"

String chipId = String(ESP.getChipId(),HEX);

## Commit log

2017-06-11 Add board
    [wifilamp.brd, wifilamp.sch]
2017-06-11 Add factory reset functionality
    [lm-wifilamp.ino, x10_wifi.ino, x20_logic.ino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]
2017-06-12 Wait for button release before turnoff
2017-06-12 Add button debug define
2017-06-13 Refresh led strip in each tick
2017-08-26 [Firmware] Touch button can be disabled
2017-08-26 [Firmware] Add current ssid to scan response
2017-08-27 [Web] Fix save button size
2017-08-29 [Web] Filter out identical network SSIDs
2017-08-31 [Firmware] Add support for regular button
2017-08-31 [STL] Add 3d printed parts
    [lamp-base.scad, lamp-base.stl, lamp-button.scad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]
2017-11-12 [Board] update board files to rev 2
    [wifilamp.sch, wifilamp2.brd, wifilamp2.sch]
2017-11-12 [Firmware] Main sketch uses touch sensor now
2017-11-12 [Web] Convert inputs and button to proper forms
2017-11-12 [Firmware] Restart device with 6sec button press
2017-11-19 [STL] Remove old models and add model v2
    [lamp-base.scad, lamp-base.stl, lamp-button.scad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]
2017-12-14 [firmware] fix missing endlines in error jsons
    [x61_server_api.ino]
2018-02-08 [Firmware] Use UART on pin D4 for LED strip control
2018-03-04 [board] Update board to rev 2.1
    [wifilamp2a.brd, wifilamp2a.sch]
2018-06-28 [STL] Update model files
    [button.scad, button.stl, lamp.scad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]
2018-06-28 [Board] Update to rev3
    [powerstrip.brd, powerstrip.sch, wifilamp2a.brd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]
2018-06-28 [Info] Update assembly instructions
2018-06-28 [Info] Add final button box photo
2018-06-28 [STL] Increase button diameter
    [button.scad, button.stl]
2018-08-27 [Firmware] Remove old defines, simplify connection and reset process
    [lm-wifilamp.ino, x05_pixels.ino, x10_wifi.ino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]
2018-08-29 [Info] Update assembly pictures

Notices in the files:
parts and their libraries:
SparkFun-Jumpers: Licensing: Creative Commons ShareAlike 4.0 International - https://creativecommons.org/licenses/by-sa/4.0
